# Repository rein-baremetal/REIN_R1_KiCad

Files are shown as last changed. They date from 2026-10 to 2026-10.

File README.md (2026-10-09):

# REIN_R1 Hardware Design (KiCad 8.0+)
REIN_R1_placement_preview

Welcome to the **REIN_R1** open-source PCB hardware project, part of the [REIN Baremetal](https://github.com/rein-baremetal) organization!

REIN_R1 is a multi-controller embedded development board built specifically for baremetal development, dual-architecture real-time control, and high-reliability embedded system experiments.

---

## What Makes REIN_R1 Stand Out?

Unlike standard single-SoC maker boards or basic evaluation kits, REIN_R1 combines high-performance coprocessing, rich peripheral interfacing, and power flexibility on a single compact 4-layer PCB:

* **Dual Microcontroller Co-Processing Architecture:** Integrates dual MCUs on-board to allow simultaneous execution of dedicated real-time control loops alongside higher-level communication and application tasks.
* **On-Board High-Speed QSPI Storage:** Dedicated QSPI flash interface configured for fast memory-mapped execution (XIP) and rapid firmware assets retrieval.
* **Integrated Hardware USB Hub:** Built-in multi-port USB hub logic eliminates external debug adapters, handling simultaneous programming, serial telemetry, and peripheral expansion over a single USB-C connection.
* **Robust Multi-Rail Power Management:** Features protected power input, integrated buck regulation, dedicated low-noise analog power paths (`3V3_A`), and smart battery/line switching (`VSYS`, `VIN`, `VBAT`).
* **Flexible Expansion & Communication:** Exposes dedicated SPI, I2C, UART, ADC channels, and GPIO arrays directly mapped for fast baremetal driver development without hardware bottlenecks.

---

## Current PCB Status

- **Schematic (`REIN_R1.kicad_sch`):** 100% Complete & Verified
- **Footprints & Symbol Libraries:** Custom library included (`REIN.kicad_sym`, `REIN.pretty/`)
- **Component Placement (`REIN_R1.kicad_pcb`):** 100% Complete
- **Routing:** **In Progress (Help Needed!)**

We are seeking open-source collaborators, hardware engineers, and layout enthusiasts to help route the remaining traces and achieve a 100% routed board that passes KiCad DRC with zero errors.

---

## Technical Specifications & Constraints

- **Board Layers:** 4 Layers (`F.Cu`, `In1.Cu` - GND, `In2.Cu` - Power Fills, `B.Cu`)
- **Default Track Width:** 0.20 mm (8 mil)
- **Default Track Clearance:** 0.20 mm (8 mil)
- **Minimum SMD Clearance:** 0.05 mm
- **Via Drill/Size:** Standard 0.3 mm / 0.6 mm

### Critical Routing Guidelines
1. **USB Differential Pairs (`/USB_DM_*`, `/USB_DP_*`):** Keep trace lengths matched and route as 90 Ω differential pairs. Minimize layer changes.
2. **QSPI Lines (`/QSPI_SCLK_*`, `/QSPI_SD0_*` to `/QSPI_SD3_*`, `/QSPI_SS_*`):** Length-match bus signals where feasible between MCU and flash storage. Keep tracks direct.
3. **Oscillator Traces (`/XIN_*`, `/XOUT_*`):** Keep routes as short as possible and isolate with ground pour fills.
4. **Power & Ground (`/GND`, `/3V3`, `/5V`, `/VIN`, `/VSYS`):** Ensure `In1.Cu` and `In2.Cu` ground planes maintain continuous connectivity without creating starved thermal islands on power/GND pads. Recalculate filled zones (`Ctrl + B`) after routing.

---

## How to Collaborate & Route

You can participate using either **KiCad PCB Editor** or **Freerouting**:

### Option A: Interactive Routing in KiCad
1. Clone or fork this repository:
   ```bash
   git clone https://github.com/rein-baremetal/REIN_R1_KiCad.git

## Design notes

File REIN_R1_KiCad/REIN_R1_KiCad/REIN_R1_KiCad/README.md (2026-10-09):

 
## Files
REIN_R1.kicad_pro / .kicad_sch / .kicad_pcb, REIN.kicad_sym (+ sym-lib-table), REIN.pretty (+ fp-lib-table), BOM, net table, GPIO map, tools/gen.py

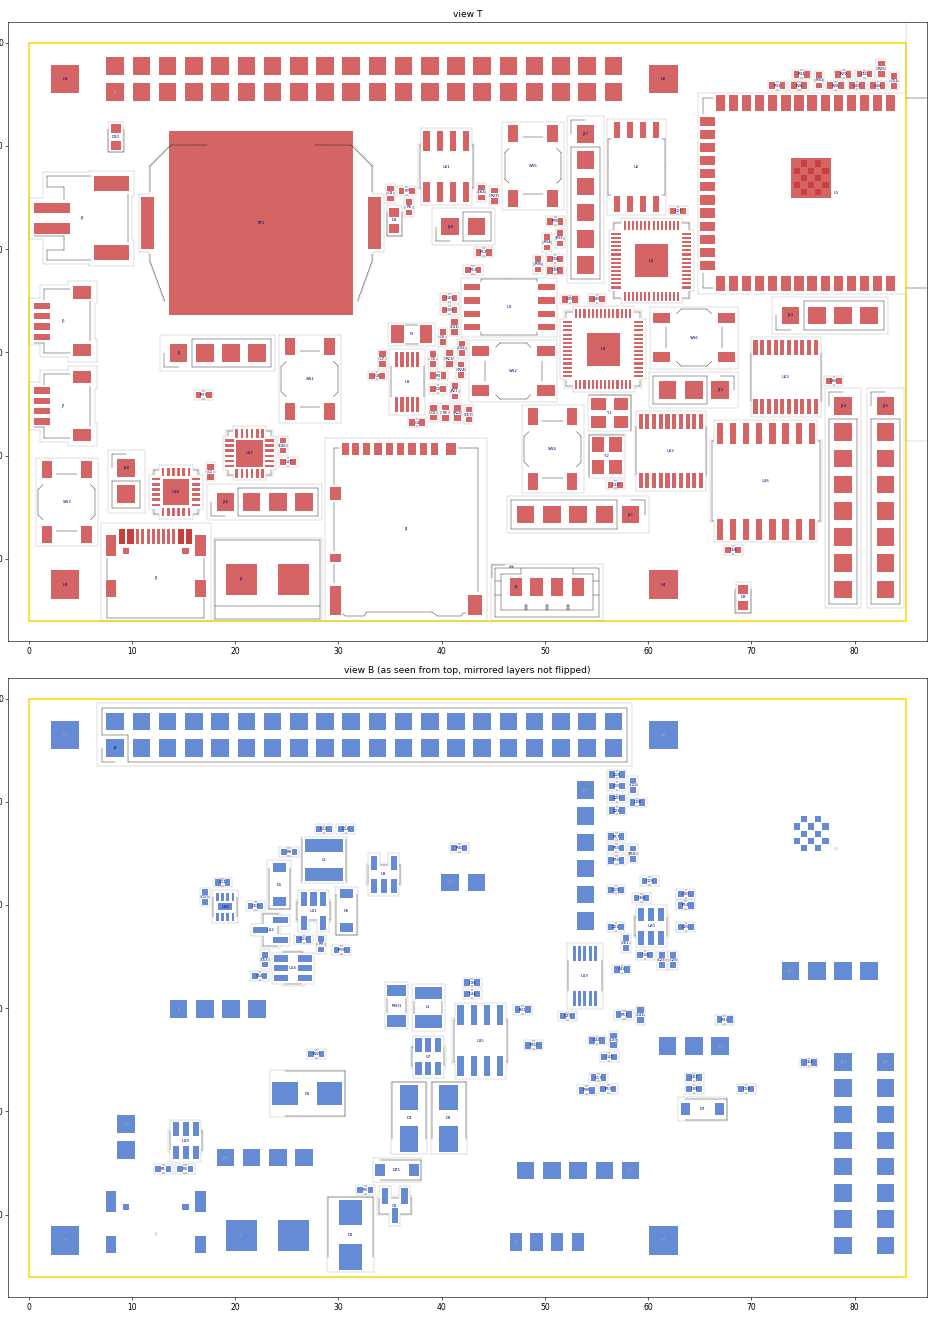
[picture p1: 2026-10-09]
REIN_R1_KiCad/REIN_R1_KiCad/REIN_R1_KiCad/REIN_R1_placement_preview.png

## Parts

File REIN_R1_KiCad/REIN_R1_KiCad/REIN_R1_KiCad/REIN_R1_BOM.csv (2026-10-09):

Ref | Value | Footprint | DNP | Confidence | Note
J1 | USB-C (HRO TYPE-C-31-M-12) | REIN:USB_C_Receptacle_HRO_TYPE-C-31-M-12 |  | ok
R1 | 5.1k | Resistor_SMD:R_0402_1005Metric | yes | ok | Fit ONLY if PD controller U18 is removed
R2 | 5.1k | Resistor_SMD:R_0402_1005Metric | yes | ok | Fit ONLY if PD controller U18 is removed
D1 | SMBJ24A | Diode_SMD:D_SMB |  | ok
U19 | USBLC6-2SC6 | Package_TO_SOT_SMD:SOT-23-6 |  | ok
U18 | STUSB4500 (QFN-24) | Package_DFN_QFN:QFN-24-1EP_4x4mm_P0.5mm_EP2.6x2.6mm |  | VERIFY | Generic pin order - replace with datasheet pinout
C1 | 100n | Capacitor_SMD:C_0402_1005Metric |  | ok
J2 | DC IN 6-36V | REIN:TerminalBlock_bornier-2_P5.08mm |  | ok
D2 | SMBJ33A | Diode_SMD:D_SMB |  | ok
Q1 | P-MOSFET 40V (reverse protect) | Package_TO_SOT_SMD:SOT-23 |  | ok
R3 | 100k | Resistor_SMD:R_0402_1005Metric |  | ok
DZ1 | BZX84-10V | Diode_SMD:D_SOD-123 |  | ok
D3 | SS34 | Diode_SMD:D_SMA |  | ok
D4 | SS34 | Diode_SMD:D_SMA |  | ok
C2 | 10u | Capacitor_SMD:C_0402_1005Metric |  | ok
C3 | 10u | Capacitor_SMD:C_0402_1005Metric |  | ok
U7 | Wide-in buck 5V (TPS54202-class) | Package_TO_SOT_SMD:SOT-23-6 |  | VERIFY | Pin order from TPS54202 family - verify; check 36V rating of final part
C4 | 100n | Capacitor_SMD:C_0402_1005Metric |  | ok
L1 | 10u | Inductor_SMD:L_1210_3225Metric |  | ok
U8 | INA226AIDGSR | REIN:VSSOP-10_3x3mm_P0.5mm |  | ok
C5 | 100n | Capacitor_SMD:C_0402_1005Metric |  | ok
R4 | 732k | Resistor_SMD:R_0402_1005Metric |  | ok
R5 | 100k | Resistor_SMD:R_0402_1005Metric |  | ok
C6 | 22u | Capacitor_SMD:C_0402_1005Metric |  | ok
F1 | PTC 2A | Fuse:Fuse_1206_3216Metric |  | ok
RSH1 | 20m shunt | Resistor_SMD:R_1206_3216Metric |  | ok
D7 | SS14 | Diode_SMD:D_SOD-123 |  | ok
C7 | 10u | Capacitor_SMD:C_0402_1005Metric |  | ok
C8 | 10u | Capacitor_SMD:C_0402_1005Metric |  | ok
U9 | MCP73831T-2ACI/OT | Package_TO_SOT_SMD:SOT-23-5 |  | ok
R6 | 2k | Resistor_SMD:R_0402_1005Metric |  | ok
C9 | 10u | Capacitor_SMD:C_0402_1005Metric |  | ok
C10 | 10u | Capacitor_SMD:C_0402_1005Metric |  | ok
R7 | 1k | Resistor_SMD:R_0402_1005Metric |  | ok
D8 | CHG (red) | LED_SMD:LED_0603_1608Metric |  | ok
J3 | LiPo (JST-PH) | Connector_JST:JST_PH_S2B-PH-SM4-TB_1x02-1MP_P2.00mm_Horizontal |  | ok
U10 | MAX17048G+T10 | REIN:DFN-8-1EP_2x2mm_P0.5mm_EP0.7x1.3mm |  | VERIFY | Pin order from memory - verify against datasheet
C11 | 100n | Capacitor_SMD:C_0402_1005Metric |  | ok
D5 | SS14 | Diode_SMD:D_SOD-123 |  | ok
D6 | SS14 | Diode_SMD:D_SOD-123 |  | ok
C12 | 10u | Capacitor_SMD:C_0402_1005Metric |  | ok
U11 | TLV62569DBV | Package_TO_SOT_SMD:SOT-23-5 |  | ok
L2 | 2.2u | Inductor_SMD:L_Taiyo-Yuden_NR-40xx |  | ok
R8 | 1M | Resistor_SMD:R_0402_1005Metric |  | ok
R9 | 221k | Resistor_SMD:R_0402_1005Metric |  | ok
C13 | 22u | Capacitor_SMD:C_0402_1005Metric |  | ok
C14 | 22u | Capacitor_SMD:C_0402_1005Metric |  | ok
R10 | 1k | Resistor_SMD:R_0402_1005Metric |  | ok
D9 | PWR (green) | LED_SMD:LED_0603_1608Metric |  | ok
U1 | RP2040 | Package_DFN_QFN:QFN-56-1EP_7x7mm_P0.4mm_EP3.2x3.2mm |  | ok
U2 | W25Q128JVSIQ | REIN:SOIC-8_5.23x5.23mm_P1.27mm |  | ok
C15 | 100n | Capacitor_SMD:C_0402_1005Metric |  | ok
Y1 | 12MHz | Crystal:Crystal_SMD_3225-4Pin_3.2x2.5mm |  | ok
R11 | 1k | Resistor_SMD:R_0402_1005Metric |  | ok
C16 | 15p | Capacitor_SMD:C_0402_1005Metric |  | ok
C17 | 15p | Capacitor_SMD:C_0402_1005Metric |  | ok
C18 | 100n | Capacitor_SMD:C_0402_1005Metric |  | ok
C19 | 100n | Capacitor_SMD:C_0402_1005Metric |  | ok
C20 | 100n | Capacitor_SMD:C_0402_1005Metric |  | ok
C21 | 100n | Capacitor_SMD:C_0402_1005Metric |  | ok
C22 | 100n | Capacitor_SMD:C_0402_1005Metric |  | ok
C23 | 100n | Capacitor_SMD:C_0402_1005Metric |  | ok
C24 | 100n | Capacitor_SMD:C_0402_1005Metric |  | ok
C25 | 100n | Capacitor_SMD:C_0402_1005Metric |  | ok
C26 | 100n | Capacitor_SMD:C_0402_1005Metric |  | ok
C27 | 100n | Capacitor_SMD:C_0402_1005Metric |  | ok
C28 | 1u | Capacitor_SMD:C_0402_1005Metric |  | ok
C29 | 1u | Capacitor_SMD:C_0402_1005Metric |  | ok
R12 | 1k | Resistor_SMD:R_0402_1005Metric |  | ok
SW1 | BOOTSEL | Button_Switch_SMD:SW_SPST_TL3342 |  | ok
SW2 | RESET | Button_Switch_SMD:SW_SPST_TL3342 |  | ok
R13 | 100k | Resistor_SMD:R_0402_1005Metric |  | ok
R14 | 100k | Resistor_SMD:R_0402_1005Metric |  | ok
C30 | 100n | Capacitor_SMD:C_0402_1005Metric |  | ok
R15 | 2.2k | Resistor_SMD:R_0402_1005Metric |  | ok
R16 | 2.2k | Resistor_SMD:R_0402_1005Metric |  | ok
R17 | 10k | Resistor_SMD:R_0402_1005Metric |  | ok
R18 | 10k | Resistor_SMD:R_0402_1005Metric |  | ok
U3 | RP2040 | Package_DFN_QFN:QFN-56-1EP_7x7mm_P0.4mm_EP3.2x3.2mm |  | ok
U4 | W25Q16JV | REIN:SOIC-8_5.23x5.23mm_P1.27mm |  | ok
C31 | 100n | Capacitor_SMD:C_0402_1005Metric |  | ok
Y2 | 12MHz | Crystal:Crystal_SMD_3225-4Pin_3.2x2.5mm |  | ok
R19 | 1k | Resistor_SMD:R_0402_1005Metric |  | ok
C32 | 15p | Capacitor_SMD:C_0402_1005Metric |  | ok
C33 | 15p | Capacitor_SMD:C_0402_1005Metric |  | ok
C34 | 100n | Capacitor_SMD:C_0402_1005Metric |  | ok
C35 | 100n | Capacitor_SMD:C_0402_1005Metric |  | ok
C36 | 100n | Capacitor_SMD:C_0402_1005Metric |  | ok
C37 | 100n | Capacitor_SMD:C_0402_1005Metric |  | ok
C38 | 100n | Capacitor_SMD:C_0402_1005Metric |  | ok
C39 | 100n | Capacitor_SMD:C_0402_1005Metric |  | ok
C40 | 100n | Capacitor_SMD:C_0402_1005Metric |  | ok
C41 | 100n | Capacitor_SMD:C_0402_1005Metric |  | ok
C42 | 100n | Capacitor_SMD:C_0402_1005Metric |  | ok
C43 | 100n | Capacitor_SMD:C_0402_1005Metric |  | ok
C44 | 1u | Capacitor_SMD:C_0402_1005Metric |  | ok
C45 | 1u | Capacitor_SMD:C_0402_1005Metric |  | ok
R20 | 1k | Resistor_SMD:R_0402_1005Metric |  | ok
SW3 | BOOTSEL | Button_Switch_SMD:SW_SPST_TL3342 |  | ok
SW4 | PROBE RESET | Button_Switch_SMD:SW_SPST_TL3342 |  | ok
R21 | 27R | Resistor_SMD:R_0402_1005Metric |  | ok
R22 | 27R | Resistor_SMD:R_0402_1005Metric |  | ok
R23 | 27R | Resistor_SMD:R_0402_1005Metric |  | ok
R24 | 27R | Resistor_SMD:R_0402_1005Metric |  | ok
U17 | USB2.0 4-port hub (CH334-class) | Package_DFN_QFN:QFN-24-1EP_4x4mm_P0.5mm_EP2.6x2.6mm |  | VERIFY | Generic pin order - replace with datasheet pinout of the chosen hub IC
C46 | 100n | Capacitor_SMD:C_0402_1005Metric |  | ok
C47 | 100n | Capacitor_SMD:C_0402_1005Metric |  | ok
U5 | ESP32-S3-WROOM-1-N8 | RF_Module:ESP32-S3-WROOM-1 |  | ok
C48 | 22u | Capacitor_SMD:C_0402_1005Metric |  | ok
C49 | 100n | Capacitor_SMD:C_0402_1005Metric |  | ok
R25 | 10k | Resistor_SMD:R_0402_1005Metric |  | ok
C50 | 1u | Capacitor_SMD:C_0402_1005Metric |  | ok
SW5 | ESP RESET | Button_Switch_SMD:SW_SPST_TL3342 |  | ok
R26 | 10k | Resistor_SMD:R_0402_1005Metric |  | ok
SW6 | ESP BOOT | Button_Switch_SMD:SW_SPST_TL3342 |  | ok
R27 | 1k | Resistor_SMD:R_0402_1005Metric |  | ok
D10 | BT / USER (blue) | LED_SMD:LED_0603_1608Metric |  | ok
J4 | microSD (Hirose DM3AT) | REIN:microSD_HC_Hirose_DM3AT-SF-PEJM5 |  | VERIFY | Pin names from memory; shield pins 10/11 to GND, DET unused
R28 | 10k | Resistor_SMD:R_0402_1005Metric |  | ok
R29 | 10k | Resistor_SMD:R_0402_1005Metric |  | ok
R30 | 10k | Resistor_SMD:R_0402_1005Metric |  | ok
R31 | 10k | Resistor_SMD:R_0402_1005Metric |  | ok
R32 | 10k | Resistor_SMD:R_0402_1005Metric |  | ok
C51 | 10u | Capacitor_SMD:C_0402_1005Metric |  | ok
U12 | REF3033 (3.3V ref) | Package_TO_SOT_SMD:SOT-23 |  | VERIFY | Pin order generic - verify; VSYS must exceed ~3.4V for regulation
C52 | 1u | Capacitor_SMD:C_0402_1005Metric |  | ok
C53 | 1u | Capacitor_SMD:C_0402_1005Metric |  | ok
C54 | 100n | Capacitor_SMD:C_0402_1005Metric |  | ok
FB1 | Ferrite 600R | Resistor_SMD:R_0402_1005Metric |  | ok
C55 | 10u | Capacitor_SMD:C_0402_1005Metric |  | ok
U13 | ADS1115IDGSR | REIN:VSSOP-10_3x3mm_P0.5mm |  | ok
C56 | 100n | Capacitor_SMD:C_0402_1005Metric |  | ok
R33 | 1k | Resistor_SMD:R_0402_1005Metric |  | ok
R34 | 1k | Resistor_SMD:R_0402_1005Metric |  | ok
R35 | 1k | Resistor_SMD:R_0402_1005Metric |  | ok
R36 | 1k | Resistor_SMD:R_0402_1005Metric |  | ok
U14 | MCP4725A1T-E/CH | Package_TO_SOT_SMD:SOT-23-6 |  | ok
R37 | 100R | Resistor_SMD:R_0402_1005Metric |  | ok
U15 | ATECC608B-SSHDA | Package_SO:SOIC-8_3.9x4.9mm_P1.27mm |  | ok
C57 | 100n | Capacitor_SMD:C_0402_1005Metric |  | ok
U16 | DS3231SN# | Package_SO:SOIC-16W_7.5x10.3mm_P1.27mm |  | ok
C58 | 100n | Capacitor_SMD:C_0402_1005Metric |  | ok
BT1 | CR1220 | Battery:BatteryHolder_Keystone_3034_1x20mm |  | ok
C59 | 100n | Capacitor_SMD:C_0402_1005Metric |  | ok
J5 | OLED 0.91in (GND VCC SCL SDA) | Connector_PinHeader_2.54mm:PinHeader_1x04_P2.54mm_Vertical |  | ok
U20 | TPS22918 (Qwiic switch) | Package_TO_SOT_SMD:SOT-23-6 |  | VERIFY | Pin order generic - verify
C60 | 100n | Capacitor_SMD:C_0402_1005Metric |  | ok
C61 | 1u | Capacitor_SMD:C_0402_1005Metric |  | ok
R38 | 4.7k | Resistor_SMD:R_0402_1005Metric |  | ok
R39 | 4.7k | Resistor_SMD:R_0402_1005Metric |  | ok
J6 | Qwiic (SH 4-pin) | Connector_JST:JST_SH_SM04B-SRSS-TB_1x04-1MP_P1.00mm_Horizontal |  | ok
J7 | Qwiic (SH 4-pin) | Connector_JST:JST_SH_SM04B-SRSS-TB_1x04-1MP_P1.00mm_Horizontal |  | ok
J8 | Grove I2C (PH 4-pin) | Connector_JST:JST_PH_B4B-PH-K_1x04_P2.00mm_Vertical |  | ok
J9 | Pi 40-pin HAT socket | Connector_PinSocket_2.54mm:PinSocket_2x20_P2.54mm_Vertical |  | ok
U21 | CAT24C32WI (HAT ID EEPROM) | Package_SO:SOIC-8_3.9x4.9mm_P1.27mm |  | ok
R40 | 10k | Resistor_SMD:R_0402_1005Metric |  | ok
C62 | 100n | Capacitor_SMD:C_0402_1005Metric |  | ok
J10 | EEPROM WP jumper (short = writable) | Connector_PinHeader_2.54mm:PinHeader_1x02_P2.54mm_Vertical |  | ok
J11 | SWD (CLK DIO GND RUN 3V3) | Connector_PinHeader_2.54mm:PinHeader_1x05_P2.54mm_Vertical |  | ok
J12 | Debug UART (GND TX RX) | Connector_PinHeader_2.54mm:PinHeader_1x03_P2.54mm_Vertical |  | ok
J13 | ESP UART (GND TX RX 3V3) | Connector_PinHeader_2.54mm:PinHeader_1x04_P2.54mm_Vertical |  | ok
U22 | TXS0108EPWR | Package_SO:TSSOP-20_4.4x6.5mm_P0.65mm |  | ok
C63 | 100n | Capacitor_SMD:C_0402_1005Metric |  | ok
C64 | 100n | Capacitor_SMD:C_0402_1005Metric |  | ok
U23 | TXS0108EPWR | Package_SO:TSSOP-20_4.4x6.5mm_P0.65mm |  | ok
C65 | 100n | Capacitor_SMD:C_0402_1005Metric |  | ok
C66 | 100n | Capacitor_SMD:C_0402_1005Metric |  | ok
R41 | 10k | Resistor_SMD:R_0402_1005Metric |  | ok
J14 | Breadboard RP2040 5V I/O (22-27, 5V, GND) | Connector_PinHeader_2.54mm:PinHeader_1x08_P2.54mm_Vertical |  | ok
J15 | Breadboard ESP32 5V I/O 1-8 | Connector_PinHeader_2.54mm:PinHeader_1x08_P2.54mm_Vertical |  | ok
J16 | Breadboard power (5V 3V3 GND GND) | Connector_PinHeader_2.54mm:PinHeader_1x04_P2.54mm_Vertical |  | ok
J17 | ADC in (AIN0-3, GND, 3V3_A) | Connector_PinHeader_2.54mm:PinHeader_1x06_P2.54mm_Vertical |  | ok
J18 | DAC out (AOUT, GND) | Connector_PinHeader_2.54mm:PinHeader_1x02_P2.54mm_Vertical |  | ok

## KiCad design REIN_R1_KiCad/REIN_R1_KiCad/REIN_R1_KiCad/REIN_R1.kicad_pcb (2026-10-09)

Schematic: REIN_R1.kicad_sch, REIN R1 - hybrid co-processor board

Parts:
BT1: CR1220; BatteryHolder_Keystone_3034_1x20mm
C1, C4, C5, C11, C15, C18, C19, C20, C21, C22, C23, C24, C25, C26, C27, C30, C31, C34, C35, C36, C37, C38, C39, C40, C41, C42, C43, C46, C47, C49, C54, C56, C57, C58, C59, C60, C62, C63, C64, C65, C66: 100n; C_0402_1005Metric
C2, C3, C7, C8, C9, C10, C12, C51, C55: 10u; C_0402_1005Metric
C6, C13, C14, C48: 22u; C_0402_1005Metric
C16, C17, C32, C33: 15p; C_0402_1005Metric
C28, C29, C44, C45, C50, C52, C53, C61: 1u; C_0402_1005Metric
D1: SMBJ24A; D_SMB
D2: SMBJ33A; D_SMB
D3, D4: SS34; D_SMA
D5, D6, D7: SS14; D_SOD-123
D8: CHG (red); LED_0603_1608Metric
D9: PWR (green); LED_0603_1608Metric
D10: BT / USER (blue); LED_0603_1608Metric
DZ1: BZX84-10V; D_SOD-123
F1: PTC 2A; Fuse_1206_3216Metric
FB1: Ferrite 600R; R_0402_1005Metric
J1: USB-C (HRO TYPE-C-31-M-12); USB_C_Receptacle_HRO_TYPE-C-31-M-12
J2: DC IN 6-36V; TerminalBlock_bornier-2_P5.08mm
J3: LiPo (JST-PH); JST_PH_S2B-PH-SM4-TB_1x02-1MP_P2.00mm_Horizontal
J4: microSD (Hirose DM3AT); microSD_HC_Hirose_DM3AT-SF-PEJM5
J5: OLED 0.91in (GND VCC SCL SDA); PinHeader_1x04_P2.54mm_Vertical
J6, J7: Qwiic (SH 4-pin); JST_SH_SM04B-SRSS-TB_1x04-1MP_P1.00mm_Horizontal
J8: Grove I2C (PH 4-pin); JST_PH_B4B-PH-K_1x04_P2.00mm_Vertical
J9: Pi 40-pin HAT socket; PinSocket_2x20_P2.54mm_Vertical
J10: EEPROM WP jumper (short = writable); PinHeader_1x02_P2.54mm_Vertical
J11: SWD (CLK DIO GND RUN 3V3); PinHeader_1x05_P2.54mm_Vertical
J12: Debug UART (GND TX RX); PinHeader_1x03_P2.54mm_Vertical
J13: ESP UART (GND TX RX 3V3); PinHeader_1x04_P2.54mm_Vertical
J14: Breadboard RP2040 5V I/O (22-27, 5V, GND); PinHeader_1x08_P2.54mm_Vertical
J15: Breadboard ESP32 5V I/O 1-8; PinHeader_1x08_P2.54mm_Vertical
J16: Breadboard power (5V 3V3 GND GND); PinHeader_1x04_P2.54mm_Vertical
J17: ADC in (AIN0-3, GND, 3V3_A); PinHeader_1x06_P2.54mm_Vertical
J18: DAC out (AOUT, GND); PinHeader_1x02_P2.54mm_Vertical
L1: 10u; L_1210_3225Metric
L2: 2.2u; L_Taiyo-Yuden_NR-40xx
Q1: P-MOSFET 40V (reverse protect); SOT-23
R1, R2: 5.1k; R_0402_1005Metric; not fitted
R3, R5, R13, R14: 100k; R_0402_1005Metric
R4: 732k; R_0402_1005Metric
R6: 2k; R_0402_1005Metric
R7, R10, R11, R12, R19, R20, R27, R33, R34, R35, R36: 1k; R_0402_1005Metric
R8: 1M; R_0402_1005Metric
R9: 221k; R_0402_1005Metric
R15, R16: 2.2k; R_0402_1005Metric
R17, R18, R25, R26, R28, R29, R30, R31, R32, R40, R41: 10k; R_0402_1005Metric
R21, R22, R23, R24: 27R; R_0402_1005Metric
R37: 100R; R_0402_1005Metric
R38, R39: 4.7k; R_0402_1005Metric
RSH1: 20m shunt; R_1206_3216Metric
SW1, SW3: BOOTSEL; SW_SPST_TL3342
SW2: RESET; SW_SPST_TL3342
SW4: PROBE RESET; SW_SPST_TL3342
SW5: ESP RESET; SW_SPST_TL3342
SW6: ESP BOOT; SW_SPST_TL3342
U1, U3: RP2040; QFN-56-1EP_7x7mm_P0.4mm_EP3.2x3.2mm
U2: W25Q128JVSIQ; SOIC-8_5.23x5.23mm_P1.27mm
U4: W25Q16JV; SOIC-8_5.23x5.23mm_P1.27mm
U5: ESP32-S3-WROOM-1-N8; ESP32-S3-WROOM-1
U7: Wide-in buck 5V (TPS54202-class); SOT-23-6
U8: INA226AIDGSR; VSSOP-10_3x3mm_P0.5mm
U9: MCP73831T-2ACI/OT; SOT-23-5
U10: MAX17048G+T10; DFN-8-1EP_2x2mm_P0.5mm_EP0.7x1.3mm
U11: TLV62569DBV; SOT-23-5
U12: REF3033 (3.3V ref); SOT-23
U13: ADS1115IDGSR; VSSOP-10_3x3mm_P0.5mm
U14: MCP4725A1T-E/CH; SOT-23-6
U15: ATECC608B-SSHDA; SOIC-8_3.9x4.9mm_P1.27mm
U16: DS3231SN#; SOIC-16W_7.5x10.3mm_P1.27mm
U17: USB2.0 4-port hub (CH334-class); QFN-24-1EP_4x4mm_P0.5mm_EP2.6x2.6mm
U18: STUSB4500 (QFN-24); QFN-24-1EP_4x4mm_P0.5mm_EP2.6x2.6mm
U19: USBLC6-2SC6; SOT-23-6
U20: TPS22918 (Qwiic switch); SOT-23-6
U21: CAT24C32WI (HAT ID EEPROM); SOIC-8_3.9x4.9mm_P1.27mm
U22, U23: TXS0108EPWR; TSSOP-20_4.4x6.5mm_P0.65mm
Y1, Y2: 12MHz; Crystal_SMD_3225-4Pin_3.2x2.5mm

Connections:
/1V1_P: C42.1, C43.1, C45.1, U3.23 (DVDD), U3.45 (VREG_VOUT), U3.50 (DVDD)
/1V1_T: C26.1, C27.1, C29.1, U1.23 (DVDD), U1.45 (VREG_VOUT), U1.50 (DVDD)
/3V3: C1.1, C5.1, C13.1, C14.1, C15.1, C18.1, C19.1, C20.1, C21.1, C22.1, C23.1, C24.1, C25.1, C28.1, C31.1, C34.1, C35.1, C36.1, C37.1, C38.1, C39.1, C40.1, C41.1, C44.1, C46.1, C47.1, C48.1, C49.1, C51.1, C57.1, C58.1, C60.1, C62.1, C63.1, C65.1, FB1.1, J4.4 (VDD), J5.2 (VCC), J11.5 (3V3), J13.4 (3V3), J16.2 (3V3), L2.2, R8.1, R10.1, R15.2, R16.2, R17.2, R18.2, R25.1, R26.1, R28.2, R29.2, R30.2, R31.2, R32.2, R40.2, R41.2, U1.1 (IOVDD), U1.10 (IOVDD), U1.22 (IOVDD), U1.33 (IOVDD), U1.42 (IOVDD), U1.43 (ADC_AVDD), U1.44 (VREG_VIN), U1.48 (USB_VDD), U1.49 (IOVDD), U2.8 (VCC), U3.1 (IOVDD), U3.10 (IOVDD), U3.22 (IOVDD), U3.33 (IOVDD), U3.42 (IOVDD), U3.43 (ADC_AVDD), U3.44 (VREG_VIN), U3.48 (USB_VDD), U3.49 (IOVDD), U4.8 (VCC), U5.2 (3V3), U8.6 (VS), U15.8 (VCC), U16.2 (VCC), U17.11 (VDD33), U18.11 (VDD), U20.1 (VIN), U21.8 (VCC), U22.2 (VCCA), U23.2 (VCCA)
/3V3_A: C55.1, C56.1, FB1.2, J17.6 (3V3A), U13.8 (VDD)
/5V: C7.1, C8.1, C9.1, C64.1, C66.1, D5.2 (A), D7.1 (K), J14.7 (5V), J16.1 (5V), R7.1, RSH1.2, U8.8 (VBUS), U8.9 (IN-), U9.4 (VDD), U22.19 (VCCB), U23.19 (VCCB)
/5V_BUCK: C6.1, F1.1, L1.2, R4.1
/5V_F: F1.2, RSH1.1, U8.10 (IN+)
/AIN0: R33.2, U13.4 (AIN0)
/AIN0_H: J17.1 (AIN0), R33.1
/AIN1: R34.2, U13.5 (AIN1)
/AIN1_H: J17.2 (AIN1), R34.1
/AIN2: R35.2, U13.6 (AIN2)
/AIN2_H: J17.3 (AIN2), R35.1
/AIN3: R36.2, U13.7 (AIN3)
/AIN3_H: J17.4 (AIN3), R36.1
/AOUT_H: J18.1 (AOUT), R37.2
/BB_22: J14.1 (IO22), U22.20 (B1)
/BB_23: J14.2 (IO23), U22.18 (B2)
/BB_24: J14.3 (IO24), U22.17 (B3)
/BB_25: J14.4 (IO25), U22.16 (B4)
/BB_26: J14.5 (IO26), U22.15 (B5)
/BB_27: J14.6 (IO27), U22.14 (B6)
/BE_1: J15.1 (E1), U23.20 (B1)
/BE_2: J15.2 (E2), U23.18 (B2)
/BE_3: J15.3 (E3), U23.17 (B3)
/BE_4: J15.4 (E4), U23.16 (B4)
/BE_5: J15.5 (E5), U23.15 (B5)
/BE_6: J15.6 (E6), U23.14 (B6)
/BE_7: J15.7 (E7), U23.13 (B7)
/BE_8: J15.8 (E8), U23.12 (B8)
/BK3_FB: R8.2, R9.1, U11.5 (FB)
/BK3_SW: L2.1, U11.3 (SW)
/BK5_BST: C4.1, U7.6 (BST)
/BK5_FB: R4.2, R5.1, U7.4 (FB)
/BK5_SW: C4.2, L1.1, U7.2 (SW)
/BOOTR_P: R20.2, SW3.1
/BOOTR_T: R12.2, SW1.1
/CC1: J1.A5, R1.1, U18.1 (CC1)
/CC2: J1.B5, R2.1, U18.2 (CC2)
/CHG_LED_A: D8.2 (A), R7.2
/CHG_PROG: R6.1, U9.5 (PROG)
/CHG_STAT: D8.1 (K), U9.1 (STAT)
/DAC_OUT: R37.1, U14.1 (VOUT)
/DBG_RX: J12.3 (RX), U1.3 (GPIO1), U3.6 (GPIO4)
/DBG_TX: J12.2 (TX), U1.2 (GPIO0), U3.7 (GPIO5)
/EE_WP: J10.1 (WP), R40.1, U21.7 (WP)
/ESP_B1: U5.4 (IO4), U23.1 (A1)
/ESP_B2: U5.5 (IO5), U23.3 (A2)
/ESP_B3: U5.6 (IO6), U23.4 (A3)
/ESP_B4: U5.7 (IO7), U23.5 (A4)
/ESP_B5: U5.8 (IO15), U23.6 (A5)
/ESP_B6: U5.9 (IO16), U23.7 (A6)
/ESP_B7: U5.10 (IO17), U23.8 (A7)
/ESP_B8: U5.11 (IO18), U23.9 (A8)
/ESP_CS: U1.28 (GPIO17), U5.18 (IO10)
/ESP_DRDY: U1.18 (GPIO15), U5.17 (IO9)
/ESP_EN: C50.1, R25.2, SW5.1, U1.31 (GPIO20), U5.3 (EN)
/ESP_HS: U1.17 (GPIO14), U5.22 (IO14)
/ESP_IO0: R26.2, SW6.1, U1.32 (GPIO21), U5.27 (IO0)
/ESP_MISO: U1.27 (GPIO16), U5.21 (IO13)
/ESP_MOSI: U1.30 (GPIO19), U5.19 (IO11)
/ESP_RXD0: J13.3 (RX), U5.36 (RXD0_IO44)
/ESP_SCK: U1.29 (GPIO18), U5.20 (IO12)
/ESP_TXD0: J13.2 (TX), U5.37 (TXD0_IO43)
/GND: BT1.2 (-), C1.2, C2.2, C3.2, C5.2, C6.2, C7.2, C8.2, C9.2, C10.2, C11.2, C12.2, C13.2, C14.2, C15.2, C16.2, C17.2, C18.2, C19.2, C20.2, C21.2, C22.2, C23.2, C24.2, C25.2, C26.2, C27.2, C28.2, C29.2, C30.2, C31.2, C32.2, C33.2, C34.2, C35.2, C36.2, C37.2, C38.2, C39.2, C40.2, C41.2, C42.2, C43.2, C44.2, C45.2, C46.2, C47.2, C48.2, C49.2, C50.2, C51.2, C52.2, C53.2, C54.2, C55.2, C56.2, C57.2, C58.2, C59.2, C60.2, C61.2, C62.2, C63.2, C64.2, C65.2, C66.2, D1.2 (A), D2.2 (A), D9.1 (K), D10.1 (K), J1.A1, J1.A12, J1.B1, J1.B12, J1.S1, J2.2 (GND), J3.2 (-), J3.MP, J4.6 (VSS), J4.10 (SH1), J4.11 (SH2), J5.1 (GND), J6.1 (GND), J6.MP, J7.1 (GND), J7.MP, J8.4 (GND), J9.6, J9.9, J9.14, J9.20, J9.25, J9.30, J9.34, J9.39, J10.2 (GND), J11.3 (GND), J12.1 (GND), J13.1 (GND), J14.8 (GND), J16.3 (GND), J16.4 (GND), J17.5 (GND), J18.2 (GND), R1.2, R2.2, R3.2, R5.2, R6.2, R9.2, R14.2, SW1.2, SW2.2, SW3.2, SW4.2, SW5.2, SW6.2, U1.19 (TESTEN), U1.57 (GND), U2.4 (GND), U3.19 (TESTEN), U3.57 (GND), U4.4 (GND), U5.1 (GND), U5.40 (GND), U5.41 (GND_EP), U7.1 (GND), U8.1 (A1), U8.2 (A0), U8.7 (GND), U9.2 (VSS), U10.3 (GND), U10.4 (QSTRT), U10.8 (CTG), U10.9 (EP), U11.2 (GND), U12.3 (GND), U13.1 (ADDR), U13.3 (GND), U14.2 (VSS), U14.6 (A0), U15.4 (GND), U16.13 (GND), U17.24 (GND), U17.25 (EP), U18.8 (ADDR0), U18.9 (ADDR1), U18.10 (RESET), U18.24 (GND), U18.25 (EP), U19.2 (GND), U20.2 (GND), U21.1 (A0), U21.2 (A1), U21.3 (A2), U21.4 (VSS), U22.11 (GND), U23.11 (GND), Y1.2 (GND), Y1.4 (GND), Y2.2 (GND), Y2.4 (GND)
/HUB_DM1: R24.1, U17.4 (DM1)
/HUB_DM2: R22.1, U17.6 (DM2)
/HUB_DP1: R23.1, U17.3 (DP1)
/HUB_DP2: R21.1, U17.5 (DP2)
/I2CA_SCL: J5.3 (SCL), R16.1, U1.7 (GPIO5), U8.5 (SCL), U10.6 (SCL), U13.10 (SCL), U14.5 (SCL), U15.6 (SCL), U16.16 (SCL), U18.6 (SCL)
/I2CA_SDA: J5.4 (SDA), R15.1, U1.6 (GPIO4), U8.4 (SDA), U10.5 (SDA), U13.9 (SDA), U14.4 (SDA), U15.5 (SDA), U16.15 (SDA), U18.5 (SDA)
/I2CQ_SCL: J6.4 (SCL), J7.4 (SCL), J8.1 (SCL), R39.1, U1.5 (GPIO3)
/I2CQ_SDA: J6.3 (SDA), J7.3 (SDA), J8.2 (SDA), R38.1, U1.4 (GPIO2)
/ID_SC: J9.28, U21.6 (SCL)
/ID_SD: J9.27, U21.5 (SDA)
/INT_PWR: R17.1, U1.8 (GPIO6), U8.3 (ALERT), U10.7 (ALRT), U18.7 (ALERT)
/LED_USR: R27.1, U5.38 (IO2)
/LED_USR_A: D10.2 (A), R27.2
/PI_5V: D7.2 (A), J9.2, J9.4
/PI_CE0: J9.24, U1.16 (GPIO13)
/PI_MISO: J9.21, U1.14 (GPIO11)
/PI_MOSI: J9.19, U1.15 (GPIO12)
/PI_RXD: J9.10, U1.11 (GPIO8)
/PI_SCLK: J9.23, U1.13 (GPIO10)
/PI_TXD: J9.8, U1.12 (GPIO9)
/PWR_LED_A: D9.2 (A), R10.2
/Q1_G: DZ1.2 (A), Q1.1 (G), R3.1
/Q3V3: C61.1, J6.2 (3V3), J7.2 (3V3), J8.3 (VCC), R38.2, R39.2, U20.6 (VOUT)
/QSPI_SCLK_P: U3.52 (QSPI_SCLK), U4.6 (CLK)
/QSPI_SCLK_T: U1.52 (QSPI_SCLK), U2.6 (CLK)
/QSPI_SD0_P: U3.53 (QSPI_SD0), U4.5 (DI/IO0)
/QSPI_SD0_T: U1.53 (QSPI_SD0), U2.5 (DI/IO0)
/QSPI_SD1_P: U3.55 (QSPI_SD1), U4.2 (DO/IO1)
/QSPI_SD1_T: U1.55 (QSPI_SD1), U2.2 (DO/IO1)
/QSPI_SD2_P: U3.54 (QSPI_SD2), U4.3 (WP#/IO2)
/QSPI_SD2_T: U1.54 (QSPI_SD2), U2.3 (WP#/IO2)
/QSPI_SD3_P: U3.51 (QSPI_SD3), U4.7 (HOLD#/IO3)
/QSPI_SD3_T: U1.51 (QSPI_SD3), U2.7 (HOLD#/IO3)
/QSPI_SS_P: R20.1, U3.56 (QSPI_SS), U4.1 (CS#)
/QSPI_SS_T: R12.1, U1.56 (QSPI_SS), U2.1 (CS#)
/QWIIC_EN: U1.40 (GPIO28_ADC2), U20.3 (ON)
/RP_IO22: U1.34 (GPIO22), U22.1 (A1)
/RP_IO23: U1.35 (GPIO23), U22.3 (A2)
/RP_IO24: U1.36 (GPIO24), U22.4 (A3)
/RP_IO25: U1.37 (GPIO25), U22.5 (A4)
/RP_IO26: U1.38 (GPIO26_ADC0), U22.6 (A5)
/RP_IO27: U1.39 (GPIO27_ADC1), U22.7 (A6)
/RTC_INT: R18.1, U1.9 (GPIO7), U16.3 (INT#/SQW)
/RTC_VBAT: BT1.1 (+), C59.1, U16.14 (VBAT)
/RUN_P: SW4.1, U3.26 (RUN)
/RUN_T: J11.4 (RUN), SW2.1, U1.26 (RUN), U3.3 (GPIO1)
/SD_CLK: J4.5 (CLK), U5.33 (IO40)
/SD_CMD: J4.3 (CMD), R32.1, U5.32 (IO39)
/SD_D0: J4.7 (DAT0), R28.1, U5.34 (IO41)
/SD_D1: J4.8 (DAT1), R29.1, U5.35 (IO42)
/SD_D2: J4.1 (DAT2), R30.1, U5.31 (IO38)
/SD_D3: J4.2 (DAT3/CD), R31.1, U5.23 (IO21)
/SWCLK: J11.1 (SWCLK), U1.24 (SWCLK), U3.4 (GPIO2)
/SWDIO: J11.2 (SWDIO), U1.25 (SWD), U3.5 (GPIO3)
/TXS_OE: R41.1, U22.10 (OE), U23.10 (OE)
/USB_DM_C: J1.A7, J1.B7, U17.2 (UP_DM), U19.3 (IO2), U19.4 (IO2b)
/USB_DP_C: J1.A6, J1.B6, U17.1 (UP_DP), U19.1 (IO1), U19.6 (IO1b)
/USB_E_DM: U5.13 (IO19_USB_DM), U17.8 (DM3)
/USB_E_DP: U5.14 (IO20_USB_DP), U17.7 (DP3)
/USB_P_DM: R22.2, U3.46 (USB_DM)
/USB_P_DP: R21.2, U3.47 (USB_DP)
/USB_T_DM: R24.2, U1.46 (USB_DM)
/USB_T_DP: R23.2, U1.47 (USB_DP)
/VBAT: C10.1, C11.1, D6.2 (A), J3.1 (+), U9.3 (VBAT), U10.1 (CELL), U10.2 (VDD)
/VBUS: D1.1 (K), D3.2 (A), J1.A4, J1.A9, J1.B4, J1.B9, U17.12 (VBUS_DET), U18.3 (VBUS_SENSE), U19.5 (VBUS)
/VDC_PROT: D4.2 (A), DZ1.1 (K), Q1.2 (S)
/VDC_RAW: D2.1 (K), J2.1 (VDC+), Q1.3 (D)
/VIN: C2.1, C3.1, D3.1 (K), D4.1 (K), U7.3 (VIN), U7.5 (EN)
/VREF_3V3: C53.1, C54.1, U12.2 (VOUT), U14.3 (VDD)
/VSYS: C12.1, C52.1, D5.1 (K), D6.1 (K), R13.1, U11.1 (EN), U11.4 (VIN), U12.1 (VIN)
/VSYS_SENSE: C30.1, R13.2, R14.1, U1.41 (GPIO29_ADC3)
/XIN_P: C32.1, U3.20 (XIN), Y2.1 (XIN)
/XIN_T: C16.1, U1.20 (XIN), Y1.1 (XIN)
/XOUT_P: R19.1, U3.21 (XOUT)
/XOUT_R_P: C33.1, R19.2, Y2.3 (XOUT)
/XOUT_R_T: C17.1, R11.2, Y1.3 (XOUT)
/XOUT_T: R11.1, U1.21 (XOUT)

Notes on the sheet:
1 USB-C + PD + hub
2 Power input + 5V
3 Charger, fuel gauge, 3V3
4 RP2040 target (main MCU)
5 RP2040 debug probe
6 USB hub + ESD
7 ESP32-S3 + microSD
8 Analog + secure + RTC
9 Bus A devices, Qwiic/Grove
10 Pi 5 HAT header + debug headers
11 Breadboard / level shifters
12 Power flags

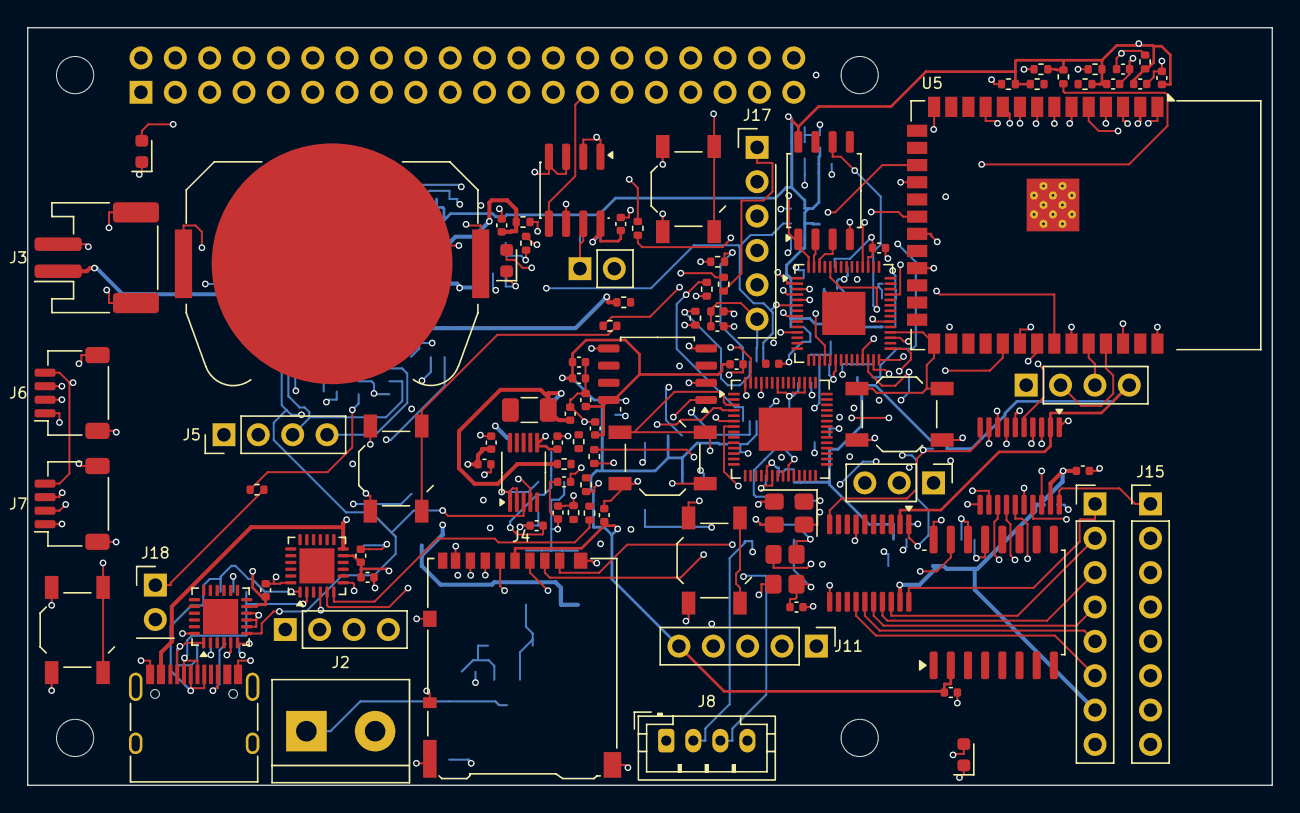
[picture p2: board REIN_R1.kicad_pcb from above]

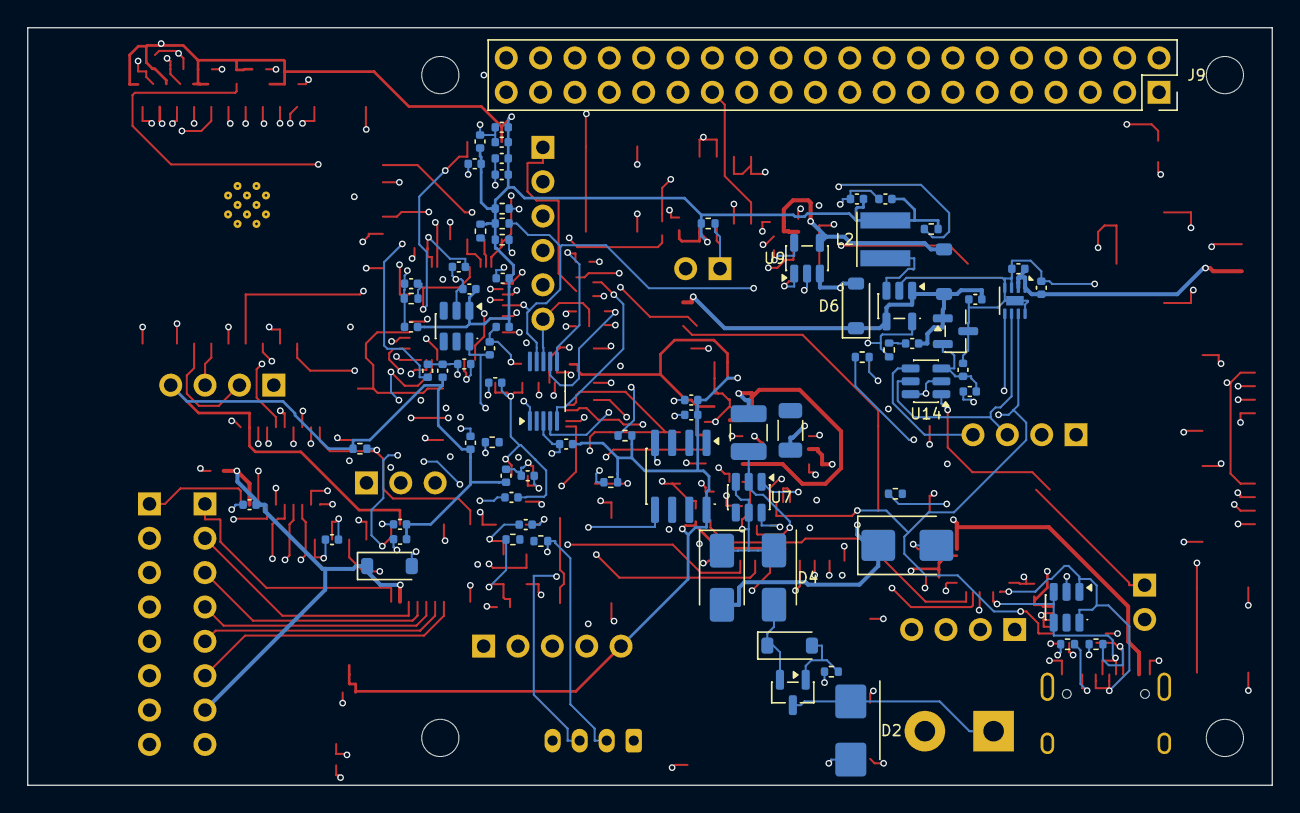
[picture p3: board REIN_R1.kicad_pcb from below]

Board: 4 copper layers, 92.0 x 56.0 mm, 177 parts (79 on the bottom side), 142 nets.

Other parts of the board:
H1, H2, H3, H4: MountingHole; MountingHole_2.75mm_M2.5_HAT

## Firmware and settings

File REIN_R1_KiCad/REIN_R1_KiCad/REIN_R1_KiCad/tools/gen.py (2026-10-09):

#!/usr/bin/env python3
"""MMARAU R1 - KiCad project generator (schematic v0.1)."""
import uuid, math, os, csv, json, re, sys, collections

OUT = sys.argv[1] if len(sys.argv) > 1 else "out"
PROJ = "REIN_R1"
ROOT = str(uuid.uuid4())
def U(): return str(uuid.uuid4())
def f(x): return ("%.4f" % x).rstrip("0").rstrip(".")

FP = dict(
    R="Resistor_SMD:R_0402_1005Metric", R12="Resistor_SMD:R_1206_3216Metric",
    C="Capacitor_SMD:C_0402_1005Metric", C8="Capacitor_SMD:C_0805_2012Metric",
    L="Inductor_SMD:L_1210_3225Metric", LS="Inductor_SMD:L_Taiyo-Yuden_NR-40xx",
    LED="LED_SMD:LED_0603_1608Metric", SW="Button_Switch_SMD:SW_SPST_TL3342",
    SMB="Diode_SMD:D_SMB", SMA="Diode_SMD:D_SMA", SOD="Diode_SMD:D_SOD-123",
    FUSE="Fuse:Fuse_1206_3216Metric", SOT23="Package_TO_SOT_SMD:SOT-23",
    SOT235="Package_TO_SOT_SMD:SOT-23-5", SOT236="Package_TO_SOT_SMD:SOT-23-6",
    QFN56="Package_DFN_QFN:QFN-56-1EP_7x7mm_P0.4mm_EP3.2x3.2mm",
    QFN24="Package_DFN_QFN:QFN-24-1EP_4x4mm_P0.5mm_EP2.6x2.6mm",
    DFN8="REIN:DFN-8-1EP_2x2mm_P0.5mm_EP0.7x1.3mm",
    SOIC8W="REIN:SOIC-8_5.23x5.23mm_P1.27mm", SOIC8="Package_SO:SOIC-8_3.9x4.9mm_P1.27mm",
    SOIC16W="Package_SO:SOIC-16W_7.5x10.3mm_P1.27mm", TSSOP20="Package_SO:TSSOP-20_4.4x6.5mm_P0.65mm",
    VSSOP10="REIN:VSSOP-10_3x3mm_P0.5mm", XTAL="Crystal:Crystal_SMD_3225-4Pin_3.2x2.5mm",
    USBC="REIN:USB_C_Receptacle_HRO_TYPE-C-31-M-12", ESP="RF_Module:ESP32-S3-WROOM-1",
    JSTPH2="Connector_JST:JST_PH_S2B-PH-SM4-TB_1x02-1MP_P2.00mm_Horizontal",
    QWIIC="Connector_JST:JST_SH_SM04B-SRSS-TB_1x04-1MP_P1.00mm_Horizontal",
    GROVE="Connector_JST:JST_PH_B4B-PH-K_1x04_P2.00mm_Vertical",
    TERM2="REIN:TerminalBlock_bornier-2_P5.08mm",
    SOCK40="Connector_PinSocket_2.54mm:PinSocket_2x20_P2.54mm_Vertical",
    SD="REIN:microSD_HC_Hirose_DM3AT-SF-PEJM5",
    BATT="Battery:BatteryHolder_Keystone_3034_1x20mm",
)
def hdr(n): return "Connector_PinHeader_2.54mm:PinHeader_1x%02d_P2.54mm_Vertical" % n

class Part:
    def __init__(s, ref, lib, value, fp, pins, sec, conf="ok", dnp=False, hide_names=False, note=""):
        s.ref, s.lib, s.value, s.fp, s.pins = ref, lib, value, fp, pins
        s.sec, s.conf, s.dnp, s.hide_names, s.note = sec, conf, dnp, hide_names, note
        s.x = s.y = 0
parts = []
cnt = collections.Counter()
def nref(p): cnt[p] += 1; return "%s%d" % (p, cnt[p])
def add(*a, **k):
    p = Part(*a, **k); parts.append(p); return p

# pin tuple: (number, name, etype, net)  etype: p passive, i power_in, o power_out
def two(ref, lib, value, fp, n1, n2, sec, names=("1", "2"), **k):
    return add(ref, lib, value, fp, [("1", names[0], "p", n1), ("2", names[1], "p", n2)], sec, hide_names=True, **k)
def R(a, b, v, sec, fp=None, **k): return two(nref("R"), "R", v, fp or FP["R"], a, b, sec, **k)
def C(a, b, v, sec, fp=None, **k): return two(nref("C"), "C", v, fp or FP["C"], a, b, sec, **k)
def L(a, b, v, sec, fp=None): return two(nref("L"), "L", v, fp or FP["L"], a, b, sec)
def D(k, a, v, fp, sec, lib="D", ref=None, **kw): return two(ref or nref("D"), lib, v, fp, k, a, sec, names=("K", "A"), **kw)
def SW(a, b, v, sec, ref=None): return two(ref or nref("SW"), "SW", v, FP["SW"], a, b, sec)
def decap(net, sec, n=1, v="100n"):
    for _ in range(n): C(net, "GND", v, sec)

def gen(ref, lib, value, fp, spec, sec, ep=None, conf="ok", note=""):
    """spec: list of (name, etype, net) numbered 1..N ; ep: net for exposed pad N+1"""
    pins = [(str(i + 1), n, t, net) for i, (n, t, net) in enumerate(spec)]
    if ep: pins.append((str(len(spec) + 1), "EP", "i", ep))
    return add(ref, lib, value, fp, pins, sec, conf=conf, note=note)

# ---------------------------------------------------------------- RP2040 block
RP_GPIO_PIN = {0:2,1:3,2:4,3:5,4:6,5:7,6:8,7:9,8:11,9:12,10:13,11:14,12:15,13:16,14:17,15:18,
               16:27,17:28,18:29,19:30,20:31,21:32,22:34,23:35,24:36,25:37,26:38,27:39,28:40,29:41}
RP_NAMES = {38:"GPIO26_ADC0",39:"GPIO27_ADC1",40:"GPIO28_ADC2",41:"GPIO29_ADC3"}
def rp2040(ref, flashref, xref, sec, sfx, gpio, usb_dp, usb_dm, swclk, swdio, run, vcc="3V3"):
    v11 = "1V1_" + sfx
    pins = {}
    for g, p in RP_GPIO_PIN.items():
        pins[p] = ("GPIO%d" % g if p not in RP_NAMES else RP_NAMES[p], "p", gpio.get(g))
    for p in (1, 10, 22, 33, 42, 49): pins[p] = ("IOVDD", "i", vcc)
    pins[19] = ("TESTEN", "p", "GND"); pins[20] = ("XIN", "p", "XIN_" + sfx); pins[21] = ("XOUT", "p", "XOUT_" + sfx)
    pins[23] = ("DVDD", "i", v11); pins[50] = ("DVDD", "i", v11)
    pins[24] = ("SWCLK", "p", swclk); pins[25] = ("SWD", "p", swdio); pins[26] = ("RUN", "p", run)
    pins[43] = ("ADC_AVDD", "i", vcc); pins[44] = ("VREG_VIN", "i", vcc); pins[45] = ("VREG_VOUT", "o", v11)
    pins[46] = ("USB_DM", "p", usb_dm); pins[47] = ("USB_DP", "p", usb_dp); pins[48] = ("USB_VDD", "i", vcc)
    pins[51] = ("QSPI_SD3", "p", "QSPI_SD3_" + sfx); pins[52] = ("QSPI_SCLK", "p", "QSPI_SCLK_" + sfx)
    pins[53] = ("QSPI_SD0", "p", "QSPI_SD0_" + sfx); pins[54] = ("QSPI_SD2", "p", "QSPI_SD2_" + sfx)
    pins[55] = ("QSPI_SD1", "p", "QSPI_SD1_" + sfx); pins[56] = ("QSPI_SS", "p", "QSPI_SS_" + sfx)
    pins[57] = ("GND", "i", "GND")
    plist = [(str(p), pins[p][0], pins[p][1], pins[p][2]) for p in sorted(pins)]
    add(ref, "RP2040", "RP2040", FP["QFN56"], plist, sec)
    # flash
    gen(flashref, "W25Q128JV", "W25Q128JVSIQ" if sfx == "T" else "W25Q16JV", FP["SOIC8W"],
        [("CS#", "p", "QSPI_SS_" + sfx), ("DO/IO1", "p", "QSPI_SD1_" + sfx), ("WP#/IO2", "p", "QSPI_SD2_" + sfx),
         ("GND", "i", "GND"), ("DI/IO0", "p", "QSPI_SD0_" + sfx), ("CLK", "p", "QSPI_SCLK_" + sfx),
         ("HOLD#/IO3", "p", "QSPI_SD3_" + sfx), ("VCC", "i", vcc)], sec)
    C(vcc, "GND", "100n", sec)
    # crystal
    add(xref, "XTAL4", "12MHz", FP["XTAL"], [("1", "XIN", "p", "XIN_" + sfx), ("2", "GND", "i", "GND"),
        ("3", "XOUT", "p", "XOUT_R_" + sfx), ("4", "GND", "i", "GND")], sec)
    R("XOUT_" + sfx, "XOUT_R_" + sfx, "1k", sec)
    C("XIN_" + sfx, "GND", "15p", sec); C("XOUT_R_" + sfx, "GND", "15p", sec)
    # decoupling
    decap(vcc, sec, 8); decap(v11, sec, 2); decap(vcc, sec, 1, "1u"); decap(v11, sec, 1, "1u")
    # bootsel
    R("QSPI_SS_" + sfx, "BOOTR_" + sfx, "1k", sec)
    SW("BOOTR_" + sfx, "GND", "BOOTSEL", sec)

# ================================================================= SECTIONS
S_USB, S_PWR, S_CHG, S_TGT, S_PRB, S_HUB, S_ESP, S_ANA, S_SYS, S_CON, S_BB, S_FLG = (
    "1 USB-C + PD + hub", "2 Power input + 5V", "3 Charger, fuel gauge, 3V3", "4 RP2040 target (main MCU)",
    "5 RP2040 debug probe", "6 USB hub + ESD", "7 ESP32-S3 + microSD", "8 Analog + secure + RTC",
    "9 Bus A devices, Qwiic/Grove", "10 Pi 5 HAT header + debug headers", "11 Breadboard / level shifters", "12 Power flags")
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

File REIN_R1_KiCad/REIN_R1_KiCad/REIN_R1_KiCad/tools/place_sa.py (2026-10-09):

import sys, math, random, json, collections
sys.path.insert(0,'/home/claude/w/tools')
import numpy as np
from geom import *
random.seed(7); np.random.seed(7)
raw,t,P=load()
PAD=0.15  # extra margin on each side of every courtyard

def is_passive(r): return (r[0] in 'RC' and r not in('RSH1',)) or r=='FB1'
MED=[r for r in P if not is_passive(r)]

# ---------- fixed placements (board-local coords) ----------
FIX={}   # ref -> (x,y,rot,side)
def edge_left(ref,cy):
    x0,y0,x1,y1=P[ref]['bbox']          # rot 90: x'=y, y'=-x
    ox=-y0; oy=cy+(x0+x1)/2
    FIX[ref]=(ox,oy,90,'T')
FIX['U5']=(78.25,14.6,270,'T')
FIX['J1']=(12.3,51.85,0,'T')
FIX['J2']=(20.6,52.0,0,'T')
FIX['J4']=(36.55,47.12,0,'T')
FIX['J8']=(47.2,52.7,0,'T')
edge_left('J3',17.0); edge_left('J6',27.0); edge_left('J7',35.2)
FIX['BT1']=(22.5,17.45,0,'T')
FIX['J15']=(83.0,35.2,0,'T'); FIX['J14']=(78.9,35.2,0,'T')

# static blockers (both sides): holes, Pi-socket
HOLES=[(3.5,3.5),(61.5,3.5),(3.5,52.5),(61.5,52.5)]
BLOCK=[(x-3.2,y-3.2,x+3.2,y+3.2) for x,y in HOLES]
J9_X0=8.37; J9_Y_EVEN=2.23; J9_Y_ODD=4.77
BLOCK.append((J9_X0-1.77,0.46,J9_X0+19*2.54+1.77,6.54))

TOP_ONLY=lambda r: r.startswith('SW') or r.startswith('J') or r=='BT1' or r in('D8','D9','D10','U1','U2','U3','U4','Y1','Y2','U16','U17','U18','U8','U22','U23','U21')
free=[r for r in MED if r not in FIX and r!='J9']
print('movable',len(free),'fixed',len(FIX))

# ---------- state arrays ----------
refs=list(FIX)+free
idx={r:i for i,r in enumerate(refs)}
N=len(refs)
st=np.zeros((N,3)); side=[ 'T']*N
for r,(x,y,th,s) in FIX.items():
    st[idx[r]]=(x,y,th); side[idx[r]]=s
nfix=len(FIX)
for r in free:
    i=idx[r]; st[i]=(random.uniform(10,60),random.uniform(8,50),random.choice([0,90,180,270]))
    side[i]='T'
sidearr=np.array([0]*N)  # 0 top,1 bottom
thtarr=np.array([1 if P[r]['tht'] else 0 for r in refs])

def bb(i):
    r=refs[i]; x,y,th=st[i]
    b=world_bbox(P[r],x,y,int(th),'B' if sidearr[i] else 'T')
    return (b[0]-PAD,b[1]-PAD,b[2]+PAD,b[3]+PAD)
B=np.array([bb(i) for i in range(N)])
BLK=np.array(BLOCK)

# nets
netpads=collections.defaultdict(list)   # net -> [(i,padindex)]
for r in refs:
    for k,(n,net,px,py,w,h) in enumerate(P[r]['pads']):
        if net and net not in('/GND',) and not net.startswith('unconnected'):
            netpads[net].append((idx[r],k))
nets=[(n,l) for n,l in netpads.items() if len({i for i,_ in l})>=2]
def wt(n,l):
    c=len(l)
    if n in('/3V3','/5V'): return 0.03
    return 1.0 if c<=8 else 0.3
netw=[wt(n,l) for n,l in nets]
part_nets=collections.defaultdict(list)
for ni,(n,l) in enumerate(nets):
    for i in {i for i,_ in l}: part_nets[i].append(ni)
PADW=[None]*N
def upd_pads(i):
    r=refs[i]; x,y,th=st[i]
    pw=pad_world(P[r],x,y,int(th),'B' if sidearr[i] else 'T')
    PADW[i]=np.array([(a[2],a[3]) for a in pw])
for i in range(N): upd_pads(i)
def net_cost(ni):
    l=nets[ni][1]
    xs=[PADW[i][k,0] for i,k in l]; ys=[PADW[i][k,1] for i,k in l]
    return netw[ni]*((max(xs)-min(xs))+(max(ys)-min(ys)))
EDGEPREF={'J5','J10','J11','J12','J13','J16','J17','J18'}
def part_cost(i):
    c=sum(net_cost(ni) for ni in part_nets[i])
    if refs[i] in EDGEPREF:
        bq=B[i]; c+=0.5*max(0,min(bq[0],bq[1],BW-bq[2],BH-bq[3]))
    # overlap
    b=B[i]
    ox=np.minimum(B[:,2],b[2])-np.maximum(B[:,0],b[0])
    oy=np.minimum(B[:,3],b[3])-np.maximum(B[:,1],b[1])
    m=(ox>0)&(oy>0)&((sidearr==sidearr[i])|(thtarr==1)|(thtarr[i]==1))
    m[i]=False
    ov=float(np.sum(np.minimum(ox[m],oy[m])*np.minimum(ox[m],oy[m]))) if m.any() else 0.0
    ov=float(np.sum(ox[m]*oy[m]))
    ox=np.minimum(BLK[:,2],b[2])-np.maximum(BLK[:,0],b[0]); oy=np.minimum(BLK[:,3],b[3])-np.maximum(BLK[:,1],b[1])
    m2=(ox>0)&(oy>0); ov+=float(np.sum(ox[m2]*oy[m2]))
    if sidearr[i]==1: c+=6.0
    oob=max(0,-b[0]+0.1)+max(0,-b[1]+0.1)+max(0,b[2]-(BW-0.1))+max(0,b[3]-(BH-0.1))
    return c, ov*30+oob*60, ov
def total():
    c=sum(net_cost(ni) for ni in range(len(nets)))
    ov=0;pen=0
    for i in range(N):
        _,p,o=part_cost(i); ov+=o; pen+=p
    return c,ov
free_idx=list(range(nfix,N))
def run(iters,T0,T1):
    global B
    T=T0; alpha=(T1/T0)**(1/iters)
    cur={i:part_cost(i) for i in range(N)}
    for it in range(iters):
        T*=alpha
        i=random.choice(free_idx)
        old=(st[i].copy(),sidearr[i],B[i].copy(),PADW[i].copy())
        mv=random.random()
        j=None
        if mv<0.55:
            st[i,0]+=random.gauss(0,max(0.25,T*1.2)); st[i,1]+=random.gauss(0,max(0.25,T*1.2))
        elif mv<0.68:
            st[i,0]=random.uniform(2,BW-2); st[i,1]=random.uniform(2,BH-2)
        elif mv<0.88:
            st[i,2]=(st[i,2]+random.choice([90,180,270]))%360
        elif mv<0.94:
            if TOP_ONLY(refs[i]): continue
            sidearr[i]^=1
        else:
            j=random.choice(free_idx)
            if j==i: continue
            oldj=(st[j].copy(),sidearr[j],B[j].copy(),PADW[j].copy())
            st[i,:2],st[j,:2]=st[j,:2].copy(),st[i,:2].copy()
        # old cost (affected)
        aff=[i]+([j] if j is not None else [])
        # evaluate affected costs before/after incl neighbors' overlap -> approximate with total over affected + nets
        before=sum(sum(cur[a][1:2]) +0 for a in aff)
        nb=set()
        for a in aff: nb.update(part_nets[a])
        cb=sum(net_cost(ni) for ni in nb)
        # overlap before: sum of overlap penalties involving aff parts (pairwise counted) -> use cur
        ob=sum(cur[a][1] for a in aff)
        for a in aff:
            B[a]=bb(a); upd_pads(a)
        ca=sum(net_cost(ni) for ni in nb)
        new={a:part_cost(a) for a in aff}
        oa=sum(new[a][1] for a in aff)
        d=(ca-cb)+(oa-ob)
        if d<=0 or random.random()<math.exp(-d/max(T,1e-6)):
            for a in aff: cur[a]=new[a]
            # neighbors' overlap costs go stale -> refresh occasionally
            if it%50==0:
                for a in range(N): cur[a]=part_cost(a)
        else:
            st[i],sidearr[i],B[i],PADW[i]=old
            if j is not None: st[j],sidearr[j],B[j],PADW[j]=oldj
        if it%20000==0:
            for a in range(N): cur[a]=part_cost(a)
            c,ov=total(); print(it,'T%.2f'%T,'wl %.0f ov %.2f'%(c,ov),flush=True)
run(int(sys.argv[1]) if len(sys.argv)>1 else 150000, 6.0, 0.05)
c,ov=total(); print('final wl %.0f overlap %.3f'%(c,ov))
res={r:(float(st[idx[r],0]),float(st[idx[r],1]),int(st[idx[r],2]),'B' if sidearr[idx[r]] else 'T') for r in refs}
json.dump(res,open('sa_result.json','w'))
